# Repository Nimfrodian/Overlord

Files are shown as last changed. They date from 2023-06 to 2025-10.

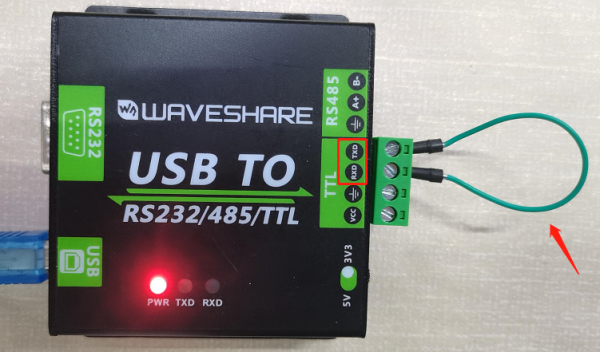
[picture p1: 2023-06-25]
Documentation/RelayBoard/Waveshare_Modbus_RTU_Relay_8ch_board/wiki webpage/Modbus RTU Relay - Waveshare Wiki_files/Serial_Module_FAQ01.png

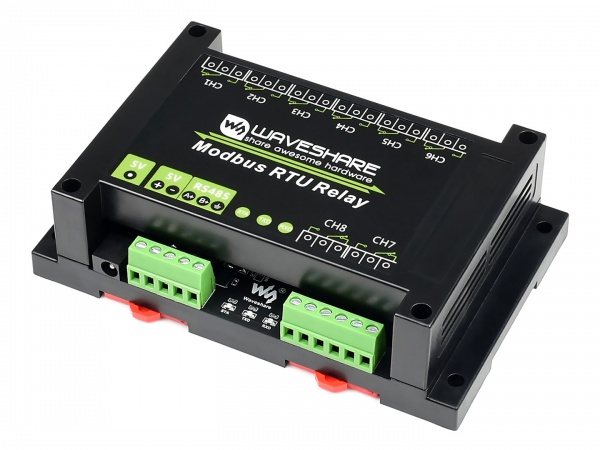
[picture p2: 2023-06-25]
Documentation/RelayBoard/Waveshare_Modbus_RTU_Relay_8ch_board/wiki webpage/Modbus RTU Relay - Waveshare Wiki_files/Modbus-RTU-Relay-1_003.jpg

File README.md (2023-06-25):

# Overlord
Code repository for the Overlord home automation system

This GitHub repository contains the code and documentation for a home automation project based on a custom board built around the ESP32-WROOM-32D processor. The board is designed to centralize home automation and provide control for various switches, low voltage devices, relay boards, power meters, and other modules. The primary goal of this project is to create a home automation system that is running as locally as possible while also providing an interface for existing home automation systems that can in turn control it in tandem.

## Features Overview
The custom board built on the ESP32 processor offers the following features:

- Digital Inputs: The board includes digital inputs that can be connected to various switches and sensors in your home. These inputs allow you to detect the state of switches and trigger automation actions based on their status.

- Digital Outputs: The board is equipped with digital outputs that can drive low voltage devices such as lights, fans, or other appliances. You can use these outputs to control the state of these devices based on your automation rules.

- Two MODBUS Lines: Two MODBUS lines are included on the board, enabling communication with relay boards and power meters. This allows you to monitor and control multiple devices and measure power consumption within your home automation system.

- CAN line: The board features a CAN (Controller Area Network) line that provides user input and control capabilities for other devices and modules. You can connect compatible devices to this line and communicate with them using the CAN protocol. This allows easy integration into any existing home automation system that supports CAN.

- Power output for other devices which can be chosen on the board and can be set to +12V, +5V, or +3.3V.

## Getting Started

To get started with this home automation project, follow these steps:

- Hardware Setup: Set up the custom board based on the ESP32 processor according to the provided documentation. Ensure that all the required connections and modules are correctly attached to the board. You can have your board easily made with the provided .7z file that you simply send to a PCB manufacturer. See Documentation for more.

- Software Setup: Install the necessary software and dependencies. This typically involves setting up the Visual Studio Code, Platformio IDE and the required libraries for programming the ESP32 board. Refer to the documentation for detailed instructions.

- Code Configuration: The code generally doesn't need modification to work. See Documentation on how the software is configured to see if you need to make any modifications.

- Upload the Code: Connect the custom board to your computer using a USB cable and upload the code to the ESP32 board using Platformio IDE the upload process for any errors and ensure successful code transfer.

- Testing and Integration: Once the code is uploaded, test the functionality of the board by interacting with the switches, devices, and modules connected to it. Verify that the digital inputs, outputs, MODBUS lines, and CAN line are working as intended.

- Customization and Expansion: Customize the code further to add additional features or integrate with other home automation systems. Expand the functionality of the project to suit your specific needs and preferences.

### Documentation
For detailed documentation, including hardware specifications, pin configurations, and usage guidelines, please refer to the Documentation folder in this repository.

### Contributing

Contributions to this home automation project are welcome! If you have ideas, suggestions, or improvements, please feel free to open an issue or submit a pull request. Let's collaborate and make home automation better together.

### License

This project is licensed under the GNU version 3.0 License. Feel free to use, modify, and distribute the code as per the terms of the license.

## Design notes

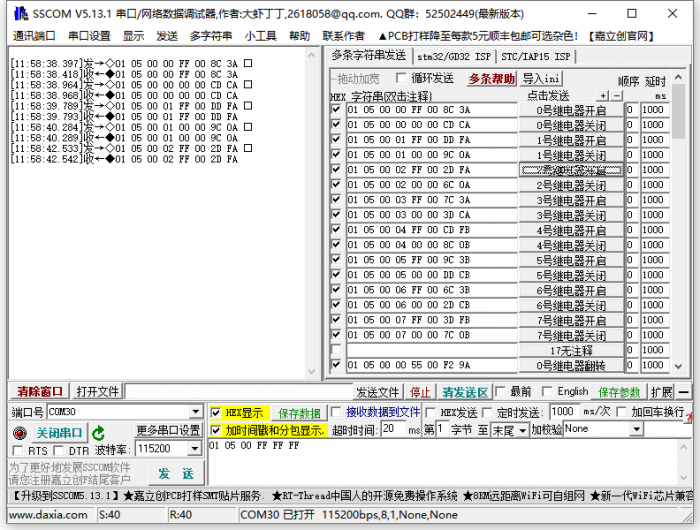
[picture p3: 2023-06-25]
Documentation/RelayBoard/Waveshare_Modbus_RTU_Relay_8ch_board/wiki webpage/Modbus RTU Relay - Waveshare Wiki_files/Modbus-RTU-Relay-2.png

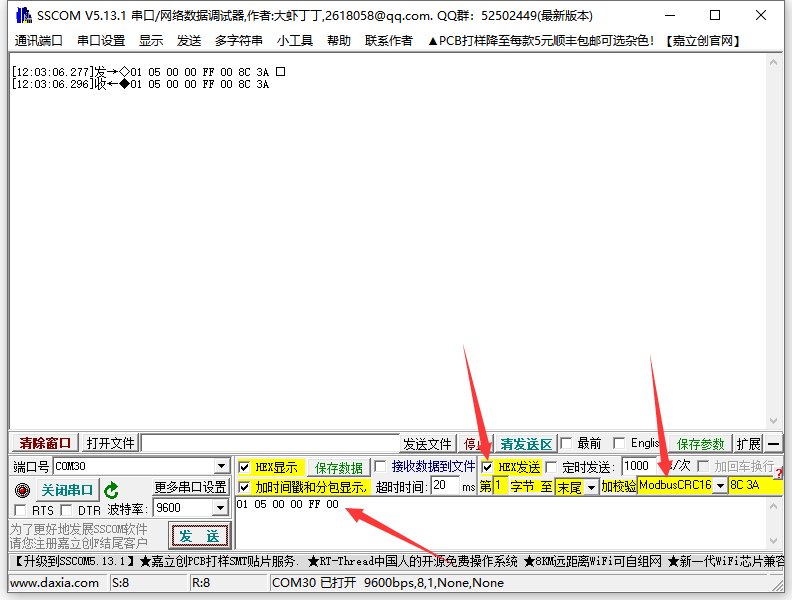
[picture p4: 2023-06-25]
Documentation/RelayBoard/Waveshare_Modbus_RTU_Relay_8ch_board/wiki webpage/Modbus RTU Relay - Waveshare Wiki_files/Modbus-RTU-Relay-3_002.png

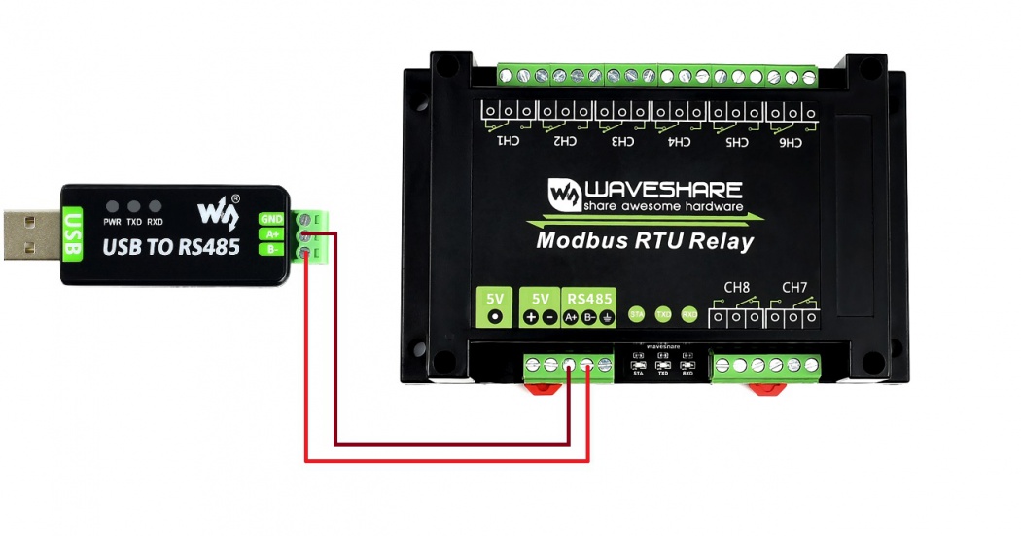
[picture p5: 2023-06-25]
Documentation/RelayBoard/Waveshare_Modbus_RTU_Relay_8ch_board/wiki webpage/Modbus RTU Relay - Waveshare Wiki_files/Modbus-RTU-Relay_connet_002.jpg

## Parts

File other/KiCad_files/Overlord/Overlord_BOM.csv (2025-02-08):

Reference | Value | Datasheet | Footprint | Qty | DNP
BOOT1,RESET1 | PTS810SJK250SMTR LFS | https://eu.mouser.com/ProductDetail/CK/PTS810SJK250SMTR-LFS?qs=Imq1NPwxi77Ow0tzRIznfA%3D%3D | OverlordCommon:PTS810SJK250SMTRLFS | 2
C1,C3,C8,C9,C12,C13,C14,C15,C16,C17,C19,C20,C21,C22,C23,C24,C25,C26,C28,C29,C30,C31,C32,C33,C34,C35,C37,C38,C39,C40,C41,C42,C43,C44,C46,C47,C48,C49,C50,C51,C52,C53 | 0.1uF | https://eu.mouser.com/ProductDetail/KYOCERA-AVX/08053C104KAT4A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 | Capacitor_SMD:C_0805_2012Metric_Pad1.18x1.45mm_HandSolder | 42
C2,C10,C11 | 10uF | https://www.mouser.se/ProductDetail/Samsung-Electro-Mechanics/CL21A106KOQNNNE?qs=349EhDEZ59qKIX0T0PKtPw%3D%3D | Capacitor_SMD:C_0805_2012Metric_Pad1.18x1.45mm_HandSolder | 3
C4,C5,C6,C7 | 1uF | https://eu.mouser.com/ProductDetail/KYOCERA-AVX/KGM21AR71E105KL?qs=Jm2GQyTW%2FbgOspZKgNqh%2Fg%3D%3D | Capacitor_SMD:C_0805_2012Metric_Pad1.18x1.45mm_HandSolder | 4
C54,C55,C56,C57 | 220uF | https://si.farnell.com/rubycon/25zl220mefc8x11-5/cap-220-f-25v-20/dp/1144699 | Capacitor_THT:CP_Radial_D8.0mm_P3.50mm | 4
D1,D2,D3,D4,D5,D6 | 1N4148 | https://www.mouser.se/ProductDetail/Taiwan-Semiconductor/TS4148-RBG?qs=5aG0NVq1C4zjFQ%2F0tPTeiA%3D%3D | Diode_SMD:D_0805_2012Metric_Pad1.15x1.40mm_HandSolder | 6
D7 | TPD2E001DZDR | https://eu.mouser.com/ProductDetail/Texas-Instruments/TPD2E001DZDR?qs=6kmNHVaEmPhk6KdNbOe6jw%3D%3D | OverlordCommon:TPD2E001DZDR | 1
DB9_IN1 | 5788792-2 | https://eu.mouser.com/ProductDetail/TE-Connectivity/5788792-2?qs=3NVJH8%2FxV2%252Bs7E8tWduUkQ%3D%3D | OverlordCommon:5788792 | 1
DB9_OUT1 | 5747844-4 | https://eu.mouser.com/ProductDetail/TE-Connectivity/5747844-4?qs=x6EjVpvqMVOIOT3ErJFDOQ%3D%3D | OverlordCommon:57478444 | 1
Dbg1,Dbg2,Dbg13,Dbg14,Dbg15,Dbg16,Dbg17,Dbg18,Dbg19,Dbg20,Dbg21,Dbg22,Dbg23,Dbg24,Dbg25,Dbg26,Dbg27,Dbg39,Dbg40,Dbg41,Dbg42,Dbg43,Dbg44,Dbg45,Dbg46,Dbg47,Dbg48,Dbg60,Dbg61,Dbg62,Dbg63,Dbg64,Dbg65,Dbg66 | Connector_Conn_01x01_Male |  | Connector_PinHeader_2.54mm:PinHeader_1x01_P2.54mm_Vertical | 34
IC1,IC2,IC3,IC4 | 74HC4052D,653 | https://assets.nexperia.com/documents/data-sheet/74HC_HCT4052.pdf | 74HC4052D653 | 4
J1,J2,J3 | 39502-1011 | https://www.molex.com/webdocs/datasheets/pdf/en-us/0395021011_TERMINAL_BLOCKS.pdf | OverlordCommon:SHDRRA11W80P0X350_1X11_3990X690X920P | 3
J4 | Conn_01x12_Pin | https://www.mouser.se/ProductDetail/538-90325-0012 | Connector_Molex:Molex_Picoflex_90325-0012_2x06_P1.27mm_Vertical | 1
J5 | Conn_01x10_Pin | ~ | Connector_PinHeader_2.54mm:PinHeader_1x10_P2.54mm_Vertical | 1
J6,J7 | Conn_01x11_Pin | ~ | Connector_PinHeader_2.54mm:PinHeader_1x11_P2.54mm_Vertical | 2
J_CAN120R1 | Conn_01x02_Male | ~ | Connector_PinHeader_2.54mm:PinHeader_1x02_P2.54mm_Vertical | 1
J_JTAG1 | FTSH-105-01-S-DV-K | https://eu.mouser.com/ProductDetail/Samtec/FTSH-105-01-S-DV-K?qs=Cqqh%252BS766wmAOq95MtbXow%3D%3D | OverlordCommon:FTSH-105-XX-YYY-DV-K | 1
J_JTAG3V3_1,J_PROG3V3_1 | Conn_01x02_Pin | ~ | Connector_PinHeader_2.54mm:PinHeader_1x02_P2.54mm_Vertical | 2
J_PROG1 | FTSH-103-01-S-DV-TR | https://eu.mouser.com/ProductDetail/Samtec/FTSH-103-01-S-DV-TR?qs=Cqqh%252BS766wm4bsLlv5ihTQ%3D%3D | OverlordCommon:FTSH-103-XX-YYY-DV-TR | 1
J_USB1 | USB_B | https://si.farnell.com/1321918?CMP=e-email-sys-shipping-GLB-Product | OverlordCommon:USB | 1
MAX485ESA+T_1,MAX485ESA+T_2 | MAX485ESA+T | https://datasheets.maximintegrated.com/en/ds/MAX1487E-MAX491E.pdf | Package_SO:SO-8_3.9x4.9mm_P1.27mm | 2
R1,R9 | 240 | https://www.mouser.se/ProductDetail/Vishay-Dale/CRCW0805240RFKEA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 | Resistor_SMD:R_0805_2012Metric | 2
R2 | 120 | https://si.farnell.com/multicomp/mcwr04x1200ftl/res-120r-1-0-0625w-thick-film/dp/2447103 | Resistor_SMD:R_0805_2012Metric_Pad1.20x1.40mm_HandSolder | 1
R3 | 0R | https://www.mouser.se/ProductDetail/Vishay-Dale/CRCW08050000Z0EA | Resistor_SMD:R_0805_2012Metric_Pad1.20x1.40mm_HandSolder | 1
R4 | 390 | https://eu.mouser.com/ProductDetail/Panasonic/ERJ-P06F3900V?qs=sGAEpiMZZMvdGkrng054t2zaCLvyUXZJqk8Bx6mV9sI%3D | Resistor_SMD:R_0805_2012Metric | 1
R5,R14,R18,R24 | 20K | ~ | Resistor_SMD:R_0805_2012Metric_Pad1.20x1.40mm_HandSolder | 4
R6,R7,R8,R19,R20,R21 | 10K | ~ | Resistor_SMD:R_0805_2012Metric_Pad1.20x1.40mm_HandSolder | 6
R10,R22 | 3K3 | ~ | Resistor_SMD:R_0805_2012Metric_Pad1.20x1.40mm_HandSolder | 2
R11 | 10k | https://si.farnell.com/vishay/crcw080510k0jneaif/res-10k-5-0-125w-0805-thick-film/dp/1739242 | Resistor_SMD:R_0805_2012Metric_Pad1.20x1.40mm_HandSolder | 1
R12 | 680 |  | Resistor_SMD:R_0805_2012Metric | 1
R13,R23 | 6K8 | ~ | Resistor_SMD:R_0805_2012Metric_Pad1.20x1.40mm_HandSolder | 2
R15,R16,R17 | 220 | https://si.farnell.com/multicomp/mchvr06jtev2200/res-220r-5-0-25w-1206-thick-film/dp/2826318 | Resistor_SMD:R_0805_2012Metric_Pad1.20x1.40mm_HandSolder | 3
R25,R26,R27,R28,R29,R30,R31,R32,R33,R34,R35,R36,R37,R38,R39,R40,R41,R42,R43,R44,R45,R46,R47,R48,R49,R50,R51,R52,R53,R54,R55,R56 | 4.7k | https://www.mouser.se/ProductDetail/YAGEO/RC0805JR-074K7P | Resistor_SMD:R_0805_2012Metric_Pad1.20x1.40mm_HandSolder | 32
SN65HVD230_1 | SN65HVD230 | https://si.farnell.com/texas-instruments/sn65hvd230dr/can-transceiver-1mbps-40-to-85deg/dp/3124671 | Package_SO:SOIC-8_3.9x4.9mm_P1.27mm | 1
SYM1,SYM2,SYM3 | Terminal plug | https://www.mouser.se/ProductDetail/Molex/39500-0011?qs=XbM9o1La6yDOmN%2F9rnqtWA%3D%3D | OverlordCommon:39500-0011 | 3
U_ESP32-S3-WROOM-1U-N16_1 | ESP32S3-Wroom | https://www.mouser.se/ProductDetail/Espressif-Systems/ESP32-S3-WROOM-1U-N16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 | PCM_Espressif:ESP32-S3-WROOM-1U | 1
U_LM317_1,U_LM317_2 | LM317_SOT-223 | https://www.mouser.se/ProductDetail/Texas-Instruments/LM317DCY?qs=5BZzbFV4k2uyLTpaIDoA2Q%3D%3D | Package_TO_SOT_SMD:SOT-223-3_TabPin2 | 2
U_TRS3232EIPWR1 | TRS3232EIPWR | https://eu.mouser.com/ProductDetail/Texas-Instruments/TRS3232EIPWR?qs=0OHPnBYoB%2FnctvQznRkgWA%3D%3D | OverlordCommon:SOP65P640X120-16N | 1

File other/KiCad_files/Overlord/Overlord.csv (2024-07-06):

Source: | C:\Users\Laptop-3070\Documents\Overlord\other\KiCad_files\Overlord\Overlord.kicad_sch
Date: | 06/07/2024 11:23:18
Tool: | Eeschema 7.0.10
Generator: | C:\Program Files\KiCad\7.0\bin\scripting\plugins/bom_csv_grouped_by_value.py
Component Count: | 108
Collated Components:
Item | Qty | Reference(s) | Value | LibPart | Footprint | Datasheet | DNP | Sim.Device | Sim.Pins
1 | 1 | 120R_enable1 | Conn_01x02_Male | Connector:Conn_01x02_Pin | Connector_PinHeader_2.54mm:PinHeader_1x02_P2.54mm_Vertical | ~
2 | 1 | C1 | 100uF | Device:C_Polarized | Capacitor_SMD:C_Elec_6.3x7.7 | ~
3 | 3 | C2, C3, C17 | 10uF | Device:C_Polarized | Capacitor_THT:CP_Radial_D4.0mm_P1.50mm | ~
4 | 1 | C4 | 100nF | Device:C | Capacitor_SMD:C_1812_4532Metric_Pad1.57x3.40mm_HandSolder | ~
5 | 2 | C5, C6 | 22uF | Device:C_Polarized | Capacitor_THT:CP_Radial_D4.0mm_P1.50mm | ~
6 | 33 | C7, C8, C9, C10, C12, C14, C15, C16, C18, C19, C20, C21, C22, C23, C24, C25, C26, C28, C29, C30, C31, C32, C33, C34, C35, C36, C37, C38, C39, C40, C41, C42, C43 | 100nF | Device:C | Capacitor_THT:C_Disc_D6.0mm_W2.5mm_P5.00mm | https://si.farnell.com/multicomp/mcfyu6104z6/cap-0-1-f-50v-y5v/dp/9411887
7 | 4 | C13, C27, C44, C45 | 220uF | Device:C | Capacitor_THT:CP_Radial_D8.0mm_P3.50mm | https://si.farnell.com/rubycon/25zl220mefc8x11-5/cap-220-f-25v-20/dp/1144699
8 | 1 | D1 | 1N5819 | Device:D_Schottky | Diode_SMD:D_SOD-123 | ~
9 | 1 | D2 | D | Device:D | Diode_SMD:D_SOD-123 | https://si.farnell.com/diodes-inc/sbr1a40s1/diode-rectifier-40v-1a-sod123/dp/2061529 |  | D | 1=K 2=A
10 | 1 | ESP1 | ESP-DevKitC-V4 | MCU_Espressif_ESP32:ESP-DevKitC-V4 | Overlord:ESP32-DevKitC-V4
11 | 2 | H1, H2 | MountingHole | Mechanical:MountingHole | MountingHole:MountingHole_3.5mm | ~
12 | 1 | J1 | RJ45x2 | Overlord-cache:74HC251D,653_RJ45x2 | Connector_RJ:RJ45_Amphenol_RJHSE538X-02
13 | 3 | J2, J5, J6 | Screw_Terminal_01x09 | Connector:Screw_Terminal_01x09 | TerminalBlockCustom:TerminalBlock_9_5.08mm_inverted | ~
14 | 1 | J3 | Conn_01x12_Female | Connector_Generic_MountingPin:Conn_01x12_MountingPin | Connector_Molex:Molex_CLIK-Mate_502386-1270_1x12-1MP_P1.25mm_Horizontal | https://si.farnell.com/molex/502386-1270/connector-rcpt-12pos-1row-1-25mm/dp/1620802
15 | 1 | J4 | Screw_Terminal_01x09 | Connector:Screw_Terminal_01x09 | TerminalBlockCustom:TerminalBlock_9_5.08mm | ~
16 | 1 | J7 | USB_B | Connector:USB_B | Connector_USB:USB_B_OST_USB-B1HSxx_Horizontal | ~
17 | 1 | J8 | USB_cable | Overlord-cache:Connector_Conn_01x04_Male | Connector_PinHeader_2.54mm:PinHeader_1x04_P2.54mm_Vertical
18 | 1 | L1 | 7447709331 | Device:L | Inductor_SMD:L_12x12mm_H8mm | https://www.we-online.com/components/products/datasheet/7447709331.pdf
19 | 1 | L2 | 4.7uH | Device:L | Inductor_SMD:L_Bourns-SRU8028_8.0x8.0mm | ~
20 | 4 | Q1, Q2, Q3, Q4 | 2N7002E | Transistor_FET:2N7002E | Package_TO_SOT_SMD:SOT-23 | http://www.diodes.com/assets/Datasheets/ds30376.pdf
21 | 4 | R1, R2, R31, R33 | 5K | Device:R | Resistor_SMD:R_0805_2012Metric_Pad1.20x1.40mm_HandSolder | ~
22 | 4 | R3, R4, R5, R15 | 10K | Device:R | Resistor_SMD:R_0805_2012Metric_Pad1.20x1.40mm_HandSolder | ~
23 | 5 | R6, R13, R14, R29, R30 | 20K | Device:R | Resistor_SMD:R_1812_4532Metric_Pad1.30x3.40mm_HandSolder | ~
24 | 1 | R7 | 120 | Device:R | Resistor_SMD:R_1812_4532Metric_Pad1.30x3.40mm_HandSolder | ~
25 | 6 | R8, R11, R12, R24, R27, R28 | 10K | Device:R | Resistor_SMD:R_1812_4532Metric_Pad1.30x3.40mm_HandSolder | ~
26 | 2 | R9, R25 | 6K8 | Device:R | Resistor_SMD:R_1812_4532Metric_Pad1.30x3.40mm_HandSolder | ~
27 | 2 | R10, R26 | 3K3 | Device:R | Resistor_SMD:R_1812_4532Metric_Pad1.30x3.40mm_HandSolder | ~
28 | 3 | R16, R17, R18 | 220 | Device:R | Resistor_SMD:R_0805_2012Metric_Pad1.20x1.40mm_HandSolder | ~
29 | 8 | RN1, RN2, RN3, RN4, RN5, RN6, RN7, RN8 | Res_network 4.7kOhm | Device:R_Pack04 | Resistor_SMD:R_Array_Convex_4x0612 | https://si.farnell.com/vishay/acasa470124701p100/res-net-array-4-7kohm-0-5-1206/dp/3974779
30 | 4 | U1, U2, U3, U4 | 74HC4052D,653 | Overlord-cache:74HC251D,653_74HC4052D,653 | Package_SO:SO-16_3.9x9.9mm_P1.27mm | http://www.ti.com/lit/gpn/sn74LS153
31 | 1 | U5 | LM2575D2T-5G | Regulator_Switching:LM2575-5.0BU | Package_TO_SOT_SMD:TO-263-5_TabPin3 | http://ww1.microchip.com/downloads/en/DeviceDoc/lm2575.pdf
32 | 1 | U6 | SN65HVD230 | Interface_CAN_LIN:SN65HVD230 | Package_SO:SOIC-8_3.9x4.9mm_P1.27mm | http://www.ti.com/lit/ds/symlink/sn65hvd230.pdf
33 | 2 | U7, U9 | MAX485ESA+T | Interface_UART:MAX485E | Package_SO:SO-8_3.9x4.9mm_P1.27mm | https://datasheets.maximintegrated.com/en/ds/MAX1487E-MAX491E.pdf
34 | 1 | U8 | AP63203WU-7 | Regulator_Switching:AP63203WU | Package_TO_SOT_SMD:TSOT-23-6 | https://www.diodes.com/assets/Datasheets/AP63200-AP63201-AP63203-AP63205.pdf

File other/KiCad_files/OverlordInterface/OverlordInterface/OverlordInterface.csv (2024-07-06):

# | Reference | Qty | Value | Footprint | DNP
1 | D1 | 1 | LED_B | LED_THT:LED_D3.0mm
2 | D2 | 1 | LED_G | LED_THT:LED_D3.0mm
3 | D3 | 1 | LED_R | LED_THT:LED_D3.0mm
4 | J1 | 1 | Conn_01x12_Female | Connector_Molex:Molex_CLIK-Mate_502386-1270_1x12-1MP_P1.25mm_Horizontal
5 | J2 | 1 | DE9_Receptacle_MountingHoles_CAN | Connector_Dsub:DSUB-9_Female_Vertical_P2.77x2.84mm_MountingHoles
6 | J3, J4, J5 | 3 | DE9_Receptacle_MountingHoles_UART | Connector_Dsub:DSUB-9_Female_Vertical_P2.77x2.84mm_MountingHoles

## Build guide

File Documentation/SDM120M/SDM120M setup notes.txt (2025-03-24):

By using the button on the SDM120M and short/long pressing it, configure the device as follows

baudrate 9600
parity None ("n")
Check for ID in code

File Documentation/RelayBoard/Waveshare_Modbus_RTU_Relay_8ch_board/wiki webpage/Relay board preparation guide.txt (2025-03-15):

This guide will help you set up the Modbus RTU Relay board to function with the Overlord system

Hardware:
- Relay board
- Power supply
- USB-to-RS485 converter

0. install SSCOM program and drivers for RS485 converter

1a. connect RS485 A connector to relay board's A connector, and same for B connector
1b. connect RS485 to PC and power on relay board

2. in SSCOM, select your COM port (check drivers if not found) for the RS485 converter
3. click openCOM button to open COM port
4. select baud rate 9600
5. read the device's current address by sending 00 03 40 00 00 01. Response should be
	YY 03 02 00 YY ## ##, where YY is device address and "## ##" is the CRC
6. set device address by sending YY 06 40 00 00 XX, where XX is the new device address
7. set baudrate to 256000 by sending 01 06 20 00 00 07 
8. change baudrate setting to 256000 in program

9. confirm changes by repeating step 5 and verifying change
10. device is now ready for use

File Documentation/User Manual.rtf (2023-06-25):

DEVELOPER MANUAL
OVERLORD HOME AUTOMATION SYSTEM

For use by developers creating, contributing to and using the Overlord Home Automation System

Created by Nimfrodian
Overview

The Overlord Home Automation System is designed to facilitate a home automation system that runs locally and can offer support for Modbus and CAN based devices as well as other devices that can be controlled directly via power supply (LED strips etc.). The system can run in a standalone configuration, but it can also be controlled via CAN in tandem. Since it can be controlled externally it can thus be controlled by other home automation systems that can implement CAN, such as Home Assistant.

Index

1.
Hardware

A custom PCB was designed to fit the ESP32-WROOM-32D based microcontroller which is at the heart of the project. The ESP board was chosen for a few reasons, the main one being accessibility as the ESP board provides several crucial features, such as fast processor speed, CAN line, and several UART lines. The second major reason was cost as ESP32 boards come cheaper than the sum cost of their parts. The boards themselves, at the time of writing, come at around 8€ while just the USB-to-UART converter costs 6€ and the processor 8€. Having the ESP32 board detachable also provides easy replaceability of the board’s main component.
The ESP32 board around which the PCB was designed is the ESP32 DEVKIT V4 featuring the ESP32-WROOM-32D processor.

The PCB design can be found in the project folder
...\Overlord\other\KiCad_files\Overlord

The PCB project can be opened in the KiCAD program, which can be obtained here
https://www.kicad.org/

For the components used on the PCB refer to the BOM within KiCAD.
The housing for the PCB is CAMDENBOSS CNMB/9/KIT Plastic Enclosure, DIN Rail, Polycarbonate, 58 mm, 90 mm, 159.2 mm, IP20
https://www.camdenboss.com/camden-boss/cnmb9kit-din-rail-module-box-kit%2c-industrial-enclosure%2c-polycarbonate-enclosure/c-23/p-18747

(Add typical system overlay here)
2.
Software

In order to upload the code, the ESP32 board used in the project the following software components are needed:
- Visual Studio Code: This program is used to modify and upload the code to the board. It can be obtained here: https://code.visualstudio.com/
o Within Visual Studio Code the following extension will need to be installed. Refer to Visual Studio Code’s Extension help on how to install them.
▪ Platformio IDE: Used to compile and upload the code to the ESP32 board
▪ C/C++: (Optional) This extension implements code browsing, highlights code, adds Intellisense and more.
▪ GitLens – Git supercharger: (Optional) This extension highlights changes made to the code
- Sourcetree: (Optional, any Git program will work). Use this program to commit changes to the code repository.
- Busmaster: (Optional) Use this program to connect to the ESP32 board via CAN connection. This will require external hardware. Another option is to use TsMaster program which again will need additional hardware. You can obtain TsMaster here https://github.com/TOSUN-Shanghai/TSMaster and the hardware that is proven to work with this project here https://openlightlabs.com/collections/frontpage/products/canable-0-4
Note: as long as the device can connect to the CAN line it should be compatible with this project

The software is designed on the AUTOSAR approach where there are three layers to it, the application layer, the real time environment layer and the basic software layer. The general layout is as such
Application layer: in this layer the CAN message composing and parsing as well as Modbus message composing and parsing logic can be found.
Real Time Environment layer: this layer connects the whole software together. It is responsible for providing the application layer with relevant data and also feeding the basic software layer with its required data
Basic Software Layer: in this layer the CAN and Modbus drivers can be found.
3.
How to use the Overlord Home Automation System

The hardware features the following interfaces:
- 2x Modbus connection
- 1x CAN connection
- 32x digital input (sense towards ground)
- 6x digital output (low-side driver)
- Power output (12V, 5V, or 3.3V – can be selected via the PCB board using a 0 Ohm resistor)

The software version 1.00.00 works as follows:
- Each of the 32 digital inputs is directly connected to its corresponding relay on the 4 relay boards, i.e., when the first digital input senses ground a Modbus message will be sent for the first relay to change state. This allows for near instantaneous change of state for the corresponding line connection.
- The two Modbus lines work on different baud rates. Modbus line that works on UART0 of the ESP32 board is called Modbus 0 and works on 256000 baud rate. This line connects the Waveshare RTU Relay boards. The other Modbus line that uses UART2 of the ESP32 board connects SDM120M power meters and runs on 9600 baud rate. Both the relay boards and the SDM120M are continuously polled for information.
- The CAN line provides information on the relay states as well as power readings from the SDM120M as they become available. It also provides the interface on which the Overlord can be controlled. See the .dbc file contains more information on what kind of messages can be expected on the CAN line. The baud rate for this connection is 250kbps.
- The 6 low-side drivers can be used to power external devices. Next to them is also the power output which can be selected via a 0 Ohm resistor. This power output can also be used to power the external device (such as the Waveshare RTU Relay board).

With this configuration it is possible to have full control over the behaviour of switches throughout the home. It is possible to turn on/off devices based on automations/time, turn on blinds, AC, etc.

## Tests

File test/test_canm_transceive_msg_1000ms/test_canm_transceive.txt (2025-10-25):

#include "test_helper.h"
#include <unity.h>
#include "canm.h"
#include "rtdb.h"
#include "mdll.h"
#include <vector>
#include <cstdio>
using namespace std;

#define TEST_ti_ms_TOTAL_EXECUTION_TIME_U32 ((tU32) 50000)

static tU32 totalMsgsSent = 0;
static tU32 totalTimeRun_ms = 0;
static vector<tCANM_MSG> messages = {};

static tB (send)(const tCANM_MSG *msg)
{
    messages.push_back(*msg);
    totalMsgsSent++;
    return NO_ERROR;
};
static tB (receive)(tCANM_MSG *msg){return NO_ERROR;};

static tU32 run_canm_runnable(void)
{
    canm_transceive_run_5ms();
    totalTimeRun_ms += TEST_ti_ms_MAIN_FUNC_CYCLE_TIME_U32;
    return totalTimeRun_ms;
}

static tS32 verify_message_ID_in_vector(uint32_t msgId)
{
    for (size_t i = 0; i < messages.size(); ++i)
    {
        if (messages[i].identifier == msgId)
        {
            return static_cast<tS32>(i);
        }
    }
    return -1; // Not found
}

static void remove_message_ID_in_vector(tU32 msgId)
{
    for (size_t i = 0; i < messages.size(); ++i)
    {
        if (messages[i].identifier == msgId)
        {
            messages.erase(messages.begin() + msgId);
            return;
        }
    }
}

static void check_new_msg_tx_and_timing()
{
    messages.clear();
    for (tU8 moduleIndx = 0; moduleIndx <= CANM_MAX_PWR_METERS_U32; moduleIndx++)
    {
        for (tU8 msgIndx = 0; msgIndx < 11; msgIndx++)
        {
            tU32 id = 0x1F5 + msgIndx + moduleIndx * 11;
            rtdb_write_tF32S((tF32SEnumT)(RTDB_MBCM_X_SDM120MREADINGS_0_AF32_0 + (msgIndx * 2) + 0 + moduleIndx * 21), 0xA5*(msgIndx+1) + moduleIndx);
            if (msgIndx < 10) rtdb_write_tF32S((tF32SEnumT)(RTDB_MBCM_X_SDM120MREADINGS_0_AF32_0 + (msgIndx * 2) + 1 + moduleIndx * 21), 0x5A*(msgIndx+1) + moduleIndx);
        }
    }

    for (tU32 ti_ms_executionTime_U32  = totalTimeRun_ms;
              ti_ms_executionTime_U32 <= (TEST_ti_ms_TOTAL_EXECUTION_TIME_U32 + totalTimeRun_ms);
              ti_ms_executionTime_U32 += TEST_ti_ms_MAIN_FUNC_CYCLE_TIME_U32)
    {
        tU32 totalRuntime_ms = run_canm_runnable();

        if ((totalRuntime_ms % 10) == 0)
        {
            // no messages
        }
        if ((totalRuntime_ms % 100) == 0)
        {
            // TODO: change timing method to be independant from test ordering
            tS32 msg0x150Pos = verify_message_ID_in_vector(0x150);
            tS32 msg0x110Pos = verify_message_ID_in_vector(0x110);
            tS32 msg0x111Pos = verify_message_ID_in_vector(0x111);
            UNITY_TEST_ASSERT_EQUAL_UINT8(true, msg0x150Pos >= 0, __LINE__, "Message ID 0x150 not found");
            UNITY_TEST_ASSERT_EQUAL_UINT8(true, msg0x110Pos >= 0, __LINE__, "Message ID 0x110 not found");
            UNITY_TEST_ASSERT_EQUAL_UINT8(true, msg0x111Pos >= 0, __LINE__, "Message ID 0x111 not found");
            remove_message_ID_in_vector(0x150);
            remove_message_ID_in_vector(0x110);
            remove_message_ID_in_vector(0x111);
        }
        if ((totalRuntime_ms % 1000) == 0)
        {
            static tU8 moduleIndx = 0;
            char text[128] = {0};

            for (tU8 msgIndx = 0; msgIndx < 11; msgIndx++)
            {
                tU32 id = 0x1F5 + msgIndx + moduleIndx * 11;
                sprintf(text, "Message ID 0x%X not found at time %d ms", id, totalRuntime_ms);
                tS32 vectorMsgIndx = verify_message_ID_in_vector(id);
                UNITY_TEST_ASSERT_EQUAL_UINT8(true, vectorMsgIndx >= 0, __LINE__, text);
                tU32 firstVar =  ((messages[vectorMsgIndx].data[3] << 24) | (messages[vectorMsgIndx].data[2] << 16) | (messages[vectorMsgIndx].data[1] << 8) | (messages[vectorMsgIndx].data[0] << 0));
                tU32 secondVar = ((messages[vectorMsgIndx].data[7] << 24) | (messages[vectorMsgIndx].data[6] << 16) | (messages[vectorMsgIndx].data[5] << 8) | (messages[vectorMsgIndx].data[4] << 0));
                sprintf(text, "firstVar incorrect at time %d ms, msgIndx %d. moduleIndx %d, msgId 0x%x", totalRuntime_ms, msgIndx, moduleIndx, id);
                UNITY_TEST_ASSERT_EQUAL_FLOAT(0xA5*(msgIndx+1) + moduleIndx, *(tF32*)((void*) &firstVar), __LINE__, text);
                sprintf(text, "secondVar incorrect at time %d ms, msgIndx %d. moduleIndx %d, msgId 0x%x", totalRuntime_ms, msgIndx, moduleIndx, id);
                UNITY_TEST_ASSERT_EQUAL_FLOAT(0x5A*(msgIndx+1) + moduleIndx, *(tF32*)((void*) &secondVar), __LINE__, text);
                remove_message_ID_in_vector(id);
            }

            moduleIndx++;
            if (moduleIndx >= CANM_MAX_PWR_METERS_U32)
            {
                moduleIndx = 0;
            }
        }

        char text[128] = {0};
        if (messages.size()) sprintf(text, "Some messages are unaccounted for. First unaccounted message's ID is 0x%X. Time: %d", messages[0].identifier, totalTimeRun_ms);
        UNITY_TEST_ASSERT_EQUAL_UINT8(0, messages.size(), __LINE__, text);
    }
}

void check_for_errors_at_the_end(void)
{
    tERRH_ERRORDATA_STR expectedError = noErrorCode;
    expectedError.moduleId = MODULE_CANM;
    test_errh_isLastErrorAsExpected(expectedError);
}

int main(int argc, char **argv) {
    UNITY_BEGIN();

    tCANM_INITDATA_STR canmInitCfg_str = {
    .ti_ms_taskDelay_U32  = TEST_ti_ms_MAIN_FUNC_CYCLE_TIME_U32,
    .canm_send_callback = send,
    .canm_receive_callback = receive,
    };
    tCANM_INITDATA_STR* canmInitCfg_pstr = &canmInitCfg_str;
    canm_init(canmInitCfg_pstr);

    RUN_TEST(check_new_msg_tx_and_timing);
    RUN_TEST(check_for_errors_at_the_end);

    UNITY_END();

    return 0;
}

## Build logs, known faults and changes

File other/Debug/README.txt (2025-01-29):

To use esp-prog you must first replace the driver via Zadig

1) Run Zadig
2) Options->List all devices
3) Select Dual RS232-HS (Interface 0)
4) Replace Driver with WinUSB

Once done you can start using the debugger via PlatformIO's "Run and Debug"

To JTAG debug ESP32-S3 it is generally easiest to simply use the builtin debugger. If that is not possible an external debugger can be used
To use an external debugger an efuse must be burned. This is done by
- installing ESP-IDF
- running the CMD environment (shows up as ESP-IDF(CMD) in Windows search)
- reading and/or checking connection by running "espefuse.py --port COM16 summary" (change COM)
- burning the fuse with "espefuse.py -p COM16 burn_efuse DIS_USB_JTAG"

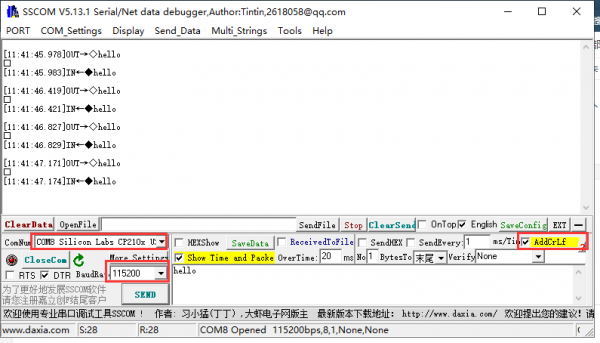
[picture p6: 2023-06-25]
Documentation/RelayBoard/Waveshare_Modbus_RTU_Relay_8ch_board/wiki webpage/Modbus RTU Relay - Waveshare Wiki_files/Serial_Module_FAQ02.png

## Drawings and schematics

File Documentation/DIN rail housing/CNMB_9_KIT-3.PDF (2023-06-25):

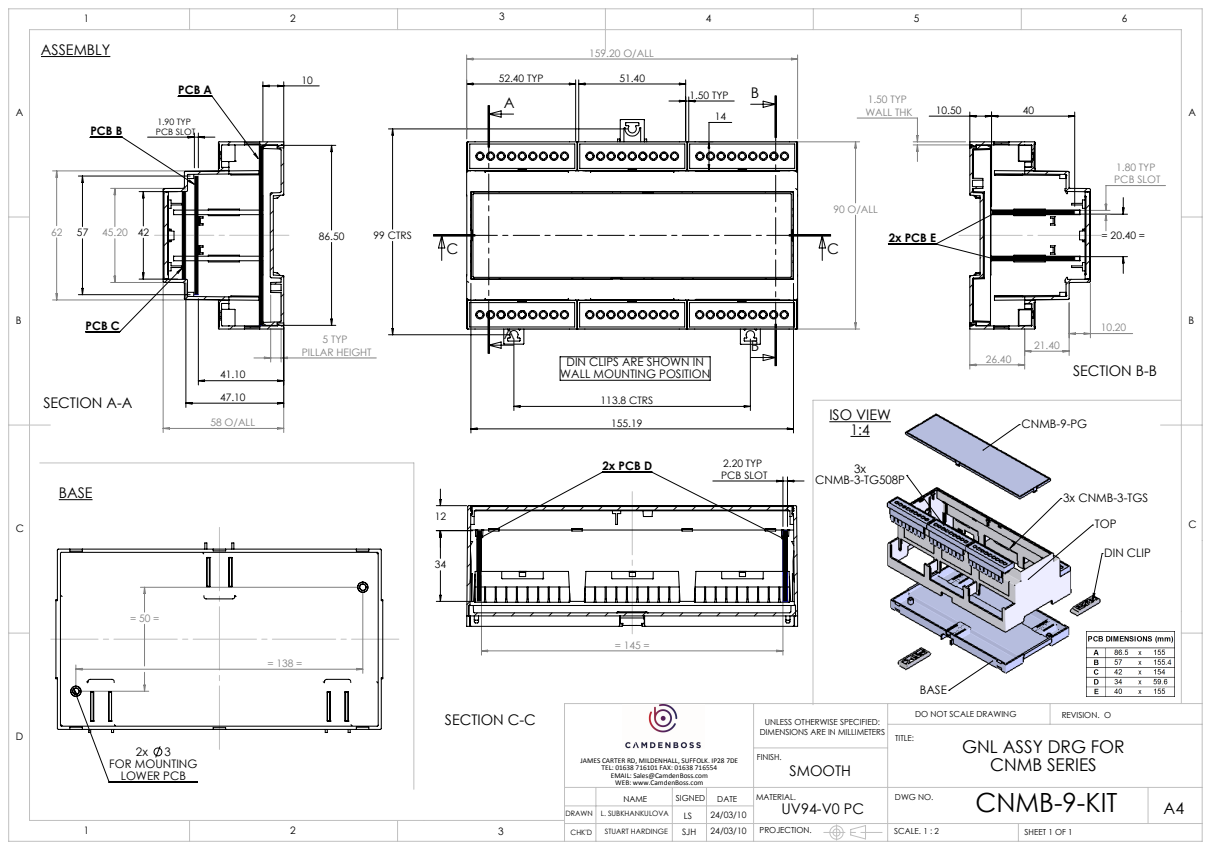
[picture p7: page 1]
90 O/ALL; 159.20 O/ALL; 113.8 CTRS; 99 CTRS; 52.40 TYP; 1.50 TYP; 5 TYP PILLAR HEIGHT; 58 O/ALL; 1.90 TYP PCB SLOT; SECTION A-A; PCB B; PCB A; PCB C; 1.50 TYP WALL THK; 1.80 TYP PCB SLOT; SECTION B-B; 2x PCB E; 2.20 TYP PCB SLOT; SECTION C-C; 2x PCB D; ISO VIEW; DIN CLIP; 3x CNMB-3-TGS; 2x 3 FOR MOUNTING LOWER PCB; NAME; SIGNED DATE; MATERIAL.; DWG NO.; SCALE. 1 : 2; SHEET 1 OF 1; REVISION. O; L. SUBKHANKULOVA; STUART HARDINGE; SJH 24/03/10

DIN CLIPS ARE SHOWN IN
WALL MOUNTING POSITION

DO NOT SCALE DRAWING
GNL ASSY DRG FOR
CNMB SERIES
CNMB-9-KIT

UNLESS OTHERWISE SPECIFIED:
DIMENSIONS ARE IN MILLIMETERS
SMOOTH

JAMES CARTER RD, MILDENHALL, SUFFOLK. IP28 7DE TEL: 01638 716101 FAX: 01638 716554 EMAIL: Sales@CamdenBoss.com

WEB: www.CamdenBoss.com

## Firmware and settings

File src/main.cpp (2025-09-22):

#include "main.h"

// Firmware version 2.xx.yy

extern "C" void app_main(void)
{
    {
        tTMRA_INITDATA_STR TmraCfg =
        {};
        tmra_init(&TmraCfg);

        tTIMH_INITDATA_STR timh_cfgData_str =
        {
            .timh_ti_us_sysTimeFunc_pfS64 = &tmra_ti_us_getCurrentTime_S64,
        };
        timh_init(&timh_cfgData_str);

        tERRH_INITDATA_STR ErrhCfg =
        {
            .ti_us_readSystemTimeCallback_S64 = tmra_ti_us_getCurrentTime_S64,
            .ti_readCurrentGlobalTimeCallback_S64 = timh_ti_readCurrentGlobalTime,
            .reportErrorCallback = ERRH_INTERNAL_CALLBACK,
        };
        errh_init(&ErrhCfg);

        tSERA_INITDATA_STR SeraCfg =
        {};
        sera_init(&SeraCfg);
        sera_print("SERA module initialized\n");

        tNVSM_INITDATA_STR NvsmCfg =
        {
            .ti_ms_taskDelay_U32 = MAIN_TI_ms_TASK_DELAY_U32, // executed in main task
        };
        nvsm_init(&NvsmCfg);
        sera_print("NVSM module initialized\n");

        tCANP_INITDATA_STR CanpCfg =
        {
            .ti_ms_taskDelay_U32 = MAIN_TI_ms_TASK_DELAY_U32, // executed in main task
        };
        canp_init(&CanpCfg);

        rtdp_init();
        sera_print("RTDB module initialized\n");

        tDMAS_INITDATA_STR DmasCfg =
        {};
        dmas_init(&DmasCfg);
        sera_print("DMAS module initialized\n");

        tDIOM_INITDATA_STR DiomCfg =
        {};
        diom_init(&DiomCfg);
        sera_print("DIOM module initialized\n");

        tMBCM_INITDATA_STR MbcmCfg =
        {};
        mbcm_init(&MbcmCfg);
        sera_print("MBCM module initialized\n");

        tDIMH_INITDATA_STR DimhCfg =
        {};
        dimh_init(&DimhCfg);
        sera_print("DIMH module initialized\n");

        sera_print("Initialization time: %lli us\n", timh_ti_us_readSystemTime_S64());
    }

    pina_setGpioAsOutput(PINA_LED_0);
    pina_setGpioAsOutput(PINA_LED_1);
    pina_setGpioAsOutput(PINA_LED_2);

    sera_print("Setting init complete LED ON\n");
    pina_setGpioLevel(PINA_LED_0, 1);

    // Main loop
    while(1)
    {
        {
            tCANM_X_CANMSGDATA_STR* rxDataPtr = canm_pstr_readCanMsgData(CAN_DMAS_COMMAND_MESSAGE);
            if (1 == rxDataPtr->canRdyForParse_tB)
            {
                dmas_canMsgParse_ev( rxDataPtr->canMsg_str.data, &rxDataPtr->canMsg_str.identifier);
                canm_x_clearFlagForCanMsgParse(CAN_DMAS_COMMAND_MESSAGE);
            }
        }

        {
            for (tU8 dmasMsgIndx = CAN_DMAS_SEND_MESSAGE0; dmasMsgIndx <= CAN_DMAS_SEND_MESSAGE15; dmasMsgIndx++)
            {
                tDMAS_MESSAGEDATA_STR preparedData = dmas_getReadyData();
                if (true == preparedData.isReady_U8)
                {
                    tCANM_X_CANMSGDATA_STR* msgPtr_pstr = canm_pstr_readCanMsgData((tCANM_CANMSGINDX_E) dmasMsgIndx);
                    msgPtr_pstr->canMsg_str.data[0] = preparedData.payload_U8[0];
                    msgPtr_pstr->canMsg_str.data[1] = preparedData.payload_U8[1];
                    msgPtr_pstr->canMsg_str.data[2] = preparedData.payload_U8[2];
                    msgPtr_pstr->canMsg_str.data[3] = preparedData.payload_U8[3];
                    msgPtr_pstr->canMsg_str.data[4] = preparedData.payload_U8[4];
                    msgPtr_pstr->canMsg_str.data[5] = preparedData.payload_U8[5];
                    msgPtr_pstr->canMsg_str.data[6] = preparedData.payload_U8[6];
                    msgPtr_pstr->canMsg_str.data[7] = preparedData.payload_U8[7];

                    msgPtr_pstr->canMsg_str.identifier = 0x20;
                    msgPtr_pstr->canRdyForTx_tB = true;
                }
                else
                {
                    break;
                }
            }
        }

        // 100ms tasks
        static uint32_t counter = 0;
        if (counter > 100)
        {
            counter = 0;
            tCANM_X_CANMSGDATA_STR* errh_canMsg0_pstr = canm_pstr_readCanMsgData(CAN_ERROR_MESSAGE0);
            tCANM_X_CANMSGDATA_STR* errh_canMsg1_pstr = canm_pstr_readCanMsgData(CAN_ERROR_MESSAGE1);
            tCANM_X_CANMSGDATA_STR* errh_canMsg2_pstr = canm_pstr_readCanMsgData(CAN_ERROR_MESSAGE2);
            tCANM_X_CANMSGDATA_STR* errh_canMsg3_pstr = canm_pstr_readCanMsgData(CAN_ERROR_MESSAGE3);

            errh_canMsg0_pstr->canMsg_str.identifier = 0x50;
            errh_canMsg1_pstr->canMsg_str.identifier = 0x51;
            errh_canMsg2_pstr->canMsg_str.identifier = 0x52;
            errh_canMsg3_pstr->canMsg_str.identifier = 0x53;

            uint8_t* canData_aU8[4] = {errh_canMsg0_pstr->canMsg_str.data,
                                    errh_canMsg1_pstr->canMsg_str.data,
                                    errh_canMsg2_pstr->canMsg_str.data,
                                    errh_canMsg3_pstr->canMsg_str.data,
                                    };

            if (true == errh_canMsgCompose_100ms(canData_aU8))
            {
                canm_x_flagCanMsgForTx(CAN_ERROR_MESSAGE0);
                canm_x_flagCanMsgForTx(CAN_ERROR_MESSAGE1);
                canm_x_flagCanMsgForTx(CAN_ERROR_MESSAGE2);
                canm_x_flagCanMsgForTx(CAN_ERROR_MESSAGE3);
            }
        }
        counter += MAIN_TI_ms_TASK_DELAY_U32;

        canm_transceive_run_5ms();

        dmas_run_5ms();

        diom_run_5ms();

        nvsm_run_5ms();

        dimh_run_5ms();

        vTaskDelay(MAIN_TI_ms_TASK_DELAY_U32 / portTICK_PERIOD_MS);
    }
}

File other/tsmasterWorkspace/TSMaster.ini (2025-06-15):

[TSMaster]
LogVerbose=6
ConfFile=D:\Projects\TOSUN\Projects\TSMaster\bin\Templates\ProjectConfigurations\CAN Bus Measurement.T7z
Bounds=1718,0,3440,1400
Maximized=0
DisplayHex=1
DisplaySym=1
Skin=
SkinPalette=
ColorfulMDI=0
Magnetic=1
TSMasterVersion=2023.9.22.972
DebugMode=0
DelConfOnFormDel=1
AutoSaveBeforeRun=0
AutoCopyDBToLocal=0
CustomFont=
TraceFont=
ShowTabGroups=1
DisableResize=0
AutoGenConstDef=0
AutoGenDBConstDef=0
DisableCrashDialog=0
UseOutputDbg=0
SelTxSgn=1
AutoHandleFlexRayUB=1
AutoSavePrj=0
DelHistoryConfOnSave=1

[OnlineReplay]
CANCount=0

[Pg0]
Count=4
f0=TfrmCANStatistics,0,52,52,257,377,141,264,349,315,1
f1=TfrmCANFDTransmit,0,0,615,863,565,375,63,1108,608,1
f2=TfrmCANFDTrace,0,0,-2,863,617,152,82,1358,523,1
f3=TfrmGraphics,0,863,-2,856,1182,157,198,936,462,1
f4=TfrmCANFDTransmit,0,0,415,1037,406,375,63,1108,608,1

[Pg1]
Count=3
f0=TfrmCANStatistics,0,741,0,765,277,141,264,349,315,1
f1=TfrmSystemMsgs,0,741,277,765,345,1013,51,853,961,1
f2=TfrmCANDatabase,0,0,0,741,622,160,133,951,594,1

[MeasurementController]
MCount=22
M0=0,1,131,-1,0,TfrmSystemMsgs,System Messages
M1=0,1,122,-1,1,TfrmCANFDTrace,CAN / CAN FD Trace
M2=0,1,50,-1,2,TfrmCANFDTransmit,CAN / CAN FD Transmit
M3=0,1,124,-1,3,TfrmGraphics,Graphics
M4=0,1,130,-1,4,TfrmCANDatabase,CAN Database
M5=0,1,128,-1,5,TfrmCANStatistics,CAN Statistics
M6=0,1,127,-1,6,TfrmLogging,Bus Logging
M7=-1,1,124,-1,7,TfrmGraphics,Deleted: Graphics
M8=-1,1,177,-1,8,TfrmNumeric,Deleted: Numeric
M9=0,1,66,-1,9,TfrmMeasurementSetup,Measurement Setup
M10=0,1,129,-1,10,TfrmPlayback,Bus Playback
M11=-1,1,124,-1,11,TfrmGraphics,Deleted: Graphics
M12=0,1,93,-1,12,TfrmSTIM,Stimulation
M13=0,1,155,-1,13,TfrmPanel,Panel
M14=0,1,146,-1,14,TfrmCCodeEditor,C Script Editor [CCode6743]
M15=0,1,180,-1,15,TfrmAutomationModule,Graphic Program 2920
M16=0,1,100,-1,16,TfrmCANoeController,CANoe Controller
M17=0,1,117,-1,17,TfrmSignalAnalyzer,Signal Comparer
M18=0,1,29,-1,18,TfrmExcelTestSystem,Excel Test Module [Test2339]
M19=0,1,47,-1,19,TfrmCalibrationCurve,Parameter Curve
M20=0,1,188,-1,20,TfrmToolboxBuilder,TOSUN Toolbox design environment
M21=0,1,15,-1,21,TfrmSystemVarMgmt,System Variable Management

[SystemMsgOptions]
MaxLines=100000
AutoStart=0
MDI=1
CaptionRenamed=0
IsExternal=0
Caption=System Messages
Priority=100
LoadMs=154
UICommon=0,-1,0,0,U3lzdGVtIE1lc3NhZ2Vz,100,157,408707419642964668
UIFilter=

[CANFDTraceOptions]
AutoStart=0
MDI=1
CaptionRenamed=0
IsExternal=0
Caption=CAN / CAN FD Trace
MaxLines=2049
DynTextColor=1
AutoScroll=1
ChronologicalMode=0
RelativeTimeMode=1
Protocol=0
Rate=2
FilterStr=
FilterIsPass=1
FilterEnabled=0
FilterChannel=0
IdRemember0=512,504,524,151,502,523,352,513,501,
IdRemember1=
IdRemember2=
IdRemember3=
IdRemember4=
IdRemember5=
IdRemember6=
IdRemember7=
IdRemember8=
IdRemember9=
IdRemember10=
IdRemember11=
IdRemember12=
IdRemember13=
IdRemember14=
IdRemember15=
IdRemember16=
IdRemember17=
IdRemember18=
IdRemember19=
IdRemember20=
IdRemember21=
IdRemember22=
IdRemember23=
IdRemember24=
IdRemember25=
IdRemember26=
IdRemember27=
IdRemember28=
IdRemember29=
IdRemember30=
IdRemember31=
TimeWidth=149
ChnWidth=39
IDWidth=66
FPSWidth=43
NameWidth=170
TypeWidth=80
DirWidth=40
DLCWidth=40
DLenWidth=90
BRSWidth=40
ESIWidth=40
DataWidth=1800
TimeVis=1
ChnVis=0
IDVis=1
FPSVis=1
NameVis=1
TypeVis=0
DirVis=1
DLCVis=0
DLenVis=0
BRSVis=0
ESIVis=0
DataVis=1
Priority=100
LoadMs=88
SyncToken=DEFAULT
CounterWidth=100
CounterVis=0
DateWidth=120
PGNWidth=112
NodeWidth=150
SrcWidth=50
DstWidth=60
PrioWidth=55
InterpWidth=200
DateVis=0
PGNVis=0
NodeVis=0
SrcVis=0
DstVis=0
PrioVis=0
InterpVis=0

[CAN_Databases]
AutoStart=0
MDI=1
CaptionRenamed=0
IsExternal=0
Caption=CAN Database
HWChnCount=2
DBFilesCount=1
DBOriCount=1
ChnCANCount=1
Priority=100
LoadMs=146
PropertyHeight=298
PropertyVisible=1
UICommon=0,-1,0,0,Q0FOIERhdGFiYXNl,100,150,3800480889012235631
UIFilter=
DBFiles0=.\DB\CAN\CAN_database.pdbc
DBOri0=..\CAN_database.dbc
ChnCAN0=0

[CANStat]
AutoStart=0
MDI=1
CaptionRenamed=0
IsExternal=0
Caption=CAN Statistics
Priority=100
LoadMs=32
UICommon=0,-1,0,0,Q0FOIFN0YXRpc3RpY3M_,100,35,51515674202303650
UIFilter=

[ChannelMappings]
CANChnCount=1
CAN0=0,0,9,0,0,-1,0,250,2000,TSMaster,
LINChnCount=0
FlexRayChnCount=0
EthernetChnCount=0

[Hardware]
ScanVendorTOSUN=0
ScanVendorVector=0
ScanVendorPeak=0
ScanVendorKvaser=0
ScanVendorZLG=0
ScanVendorIntrepidcs=0
ScanVendorCANable=1
AutoStart=0
MDI=0
CaptionRenamed=0
IsExternal=0
Caption=Hardware Configuration
Priority=100
LoadMs=77
UICommon=0,0,0,0,SGFyZHdhcmUgQ29uZmlndXJhdGlvbg__,100,88,96827417675166801
UIFilter=

[PluginManager]
ExternalCount=0

[BusStatistics]
Enabled=1

[UserVariables]
Count=0

[Debug]
OutputLeak=1

[TS_MAPPING]
AutoStart=0
MDI=0
CaptionRenamed=0
IsExternal=0
Caption=TS Channel Mapping
Priority=100
LoadMs=55
UICommon=0,0,0,0,VFMgQ2hhbm5lbCBNYXBwaW5n,100,73,5685802031077544260
UIFilter=
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

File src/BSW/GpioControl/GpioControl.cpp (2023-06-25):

#include "GpioControl.h"

static bool _gpioState[NUM_OF_INPUT_INDX] = {0};            // holds end result
static bool _gpioOutState[NUM_OF_GPIO_OUTPUTS] = {0};       // holds outputs for GPIO out abstraction
static uint8_t _gpioCntr[NUM_OF_INPUT_INDX] = {0};          // increments or decrements based on GPIO state.
static uint8_t _debounceTimer_ms[NUM_OF_INPUT_INDX] = {0};  // holds debounce timer. Decrements by task execution period each call, if not 0
const uint8_t _sortedGpioIndxs[NUM_OF_INPUT_INDX] =         // sorted array indexes. Looping _gpioState using this array as index will result in proper reading from GPIO
{
    INPUT_INDX_00,
    INPUT_INDX_01,
    INPUT_INDX_02,
    INPUT_INDX_03,
    INPUT_INDX_04,
    INPUT_INDX_05,
    INPUT_INDX_06,
    INPUT_INDX_07,
    INPUT_INDX_08,
    INPUT_INDX_09,
    INPUT_INDX_10,
    INPUT_INDX_11,
    INPUT_INDX_12,
    INPUT_INDX_13,
    INPUT_INDX_14,
    INPUT_INDX_15,
    INPUT_INDX_16,
    INPUT_INDX_17,
    INPUT_INDX_18,
    INPUT_INDX_19,
    INPUT_INDX_20,
    INPUT_INDX_21,
    INPUT_INDX_22,
    INPUT_INDX_23,
    INPUT_INDX_24,
    INPUT_INDX_25,
    INPUT_INDX_26,
    INPUT_INDX_27,
    INPUT_INDX_28,
    INPUT_INDX_29,
    INPUT_INDX_30,
    INPUT_INDX_31,
};

void CtrlGpio_init(void)
{
    // set all gpio input pins as INPUT
    for (uint8_t gpioInIndx = 0; gpioInIndx < NUM_OF_GPIO_INPUTS; gpioInIndx++)
    {
        gpio_set_direction(GPIO_IN[gpioInIndx], GPIO_MODE_INPUT);
    }

    // set all gpio selection pins as OUTPUT
    for (uint8_t gpioInSelIndx = 0; gpioInSelIndx < NUM_OF_GPIO_IN_SEL; gpioInSelIndx++)
    {
        gpio_reset_pin(GPIO_IN_SEL[gpioInSelIndx]);
        gpio_set_direction(GPIO_IN_SEL[gpioInSelIndx], GPIO_MODE_OUTPUT);
    }

    // reset all output pins functions so they can be set as OUTPUT and set them as OUTPUT
    for (uint8_t gpioOutIndx = 0; gpioOutIndx < NUM_OF_GPIO_OUTPUTS; gpioOutIndx++)
    {
        gpio_reset_pin(GPIO_OUT[gpioOutIndx]);
        gpio_set_direction(GPIO_OUT[gpioOutIndx], GPIO_MODE_OUTPUT);
    }

    // reset all debug output pins functions so they can be set as OUTPUT and set them as OUTPUT
    for (uint8_t gpioOutDbgIndx = 0; gpioOutDbgIndx < GPIO_OUT_DEBUG_NUM_OF_INDX; gpioOutDbgIndx++)
    {
        gpio_reset_pin(GPIO_OUT_DEBUG[gpioOutDbgIndx]);
        gpio_set_direction(GPIO_OUT_DEBUG[gpioOutDbgIndx], GPIO_MODE_OUTPUT);
    }

    // create reading task
    xTaskCreatePinnedToCore(
    CtrlGpio_read,    // Function that should be called
    "CtrlGpio_read",   // Name of the task (for debugging)
    8192,            // Stack size (bytes)
    NULL,            // Parameter to pass
    1,               // Task priority
    NULL,            // Task handle
    0                // run on core 0

    );

    // create writing task
    xTaskCreatePinnedToCore(
    CtrlGpio_write,     // Function that should be called
    "CtrlGpio_write",   // Name of the task (for debugging)
    1024,            // Stack size (bytes)
    NULL,            // Parameter to pass
    1,               // Task priority
    NULL,            // Task handle
    0                // run on core 0
    );
}

/**
 * @brief Function checks if input variable needs to be changed as part of debouncing
 * @param inputIndx input index of the input variable. Goes from 0 to NUM_OF_INPUT_INDX
 * @param gpioSt the current state of the input variable as read from GPIO
 * @return (void)
 */
static void checkInputForChange(CtrlGpio_inputIndxType inputIndx, bool gpioSt)
{
    // proceed if this input is not on debounce timer
    if (0 == _debounceTimer_ms[inputIndx])
    {
        // delete the appropriate counter. 0x0F bits are "1" counter, 0xF0 bits are "0" counter
        _gpioCntr[inputIndx] &= (0x0F << (4 * !gpioSt));

        // if gpio state is different than saved
        if (gpioSt != _gpioState[inputIndx])
        {
            // if previous state is different and not enough samples are yet taken then increment the appropriate counter
            if (NUM_OF_SAMPLES_FOR_STATE_CHANGE > (0x0F & (_gpioCntr[inputIndx] >> (4 * !gpioSt))))
            {
                _gpioCntr[inputIndx] += 0x01 << (4 * !gpioSt);
            }

            // save the new state as enough samples were taken and add the debounce time
            if (NUM_OF_SAMPLES_FOR_STATE_CHANGE == (0x0F & (_gpioCntr[inputIndx] >> (4 * !gpioSt))))
            {
                // save the new state
                _gpioState[inputIndx] = gpioSt;

                // set the debounce timer
                _debounceTimer_ms[inputIndx] = DEBOUNCE_TIME_MS;
            }
        }
    }
    else // debounce time is active and decrement the timer by task delay
    {
        _debounceTimer_ms[inputIndx] -= CTLR_GPIO_TASK_DELAY_TIME_MS;
    }
}
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

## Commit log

2023-06-25 FW version 1.00.00: - initial release
    [Overlord.kicad_pcb, Overlord.sch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]
2023-07-02 Reworked DIO - GPIO output now works on PWM basis, no longer just on/off - Added CAN support GPIO. GPIO input now sent to CAN and GPIO output can be controlled via CAN - minor code cleanup
    [ComModbus.cpp, main.cpp]
2023-07-16 Added support for multiple Waveshare relay boards Minor code fixes MODBUS 0 on UART0 now sends relay commands in a circular fashion as opposed to when message is ready to be sent (as MODBUS 2 on UART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
    [Overlord.sch]
2023-07-27 Fixed issue where messages would be ignored by relay boards since the Rs485 line would not go into recessive state
    [ComModbus.cpp]
2023-07-28 Fixed GPIO bitmapping issue - relays now respond to their corresponding GPIO pin
2023-08-02 Added GPIO disable control for relays
2023-09-08 Changed relay control from fast as possible to 2.5s update time with updates when needed Changed GPIO input timings
2023-12-01 Reworked UARTS - free'd up UART0, removed PWM outputs
    [ComModbus.cpp, main.cpp]
2023-12-03 Added some basic CLI now that UART0 is freed up
2023-12-03 Added time print to dev_sts
2023-12-07 renamed modbus channels to better reflect uarts behind
2023-12-13 minor fixes, updated CAN database for external dimmer module
    [ComModbus.cpp]
2023-12-15 Added LED pins for quick status display, updated schematic (still need to update PCB),
    [Overlord.kicad_pcb, Overlord.sch]
2024-02-13 Project compiles, fixed compiler warnings,
    [main.cpp]
2024-07-06 Finalised ver1.0 revC of PCB Added interface PCB
    [Overlord.csv, Overlord.kicad_pcb, Overlord.kicad_sch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]
2024-07-06 Added gerber files
    [Overlord-B_Cu.gbl, Overlord-B_Mask.gbs, Overlord-B_Paste.gbp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]
2024-07-16 Modified project to be based on az-...-V4 board, fixed Dio lib on depending on outside sources, added waveforms project
    [ComModbus.cpp, TSMaster.ini]
2024-09-14 temp changes
    [Overlord.kicad_sch]
2025-01-29 pre ESP32-S3 migration
    [Overlord.kicad_sch]
2025-02-08 sent to production
    [InputMux.kicad_sch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]
2025-02-25 sent to production with fixes
    [InputMux.kicad_sch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]
2025-03-12 updated DIO ordering due to change in hardware connections commented out crashing Rte_Cli_run() function
    [TSMaster.ini, UI.ini, main.cpp]
2025-03-15 Fixed program crashing from CLI implementation by replacing it with sera module from Dimmer Added relay board setup guide
    [ComModbus.cpp, TSMaster.ini, main.cpp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]
2025-04-13 finalised DIO module implementation TODO: fix DMAS to properly communicate via CAN
    [TSMaster.ini, UI.ini, diom.cpp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]
2025-04-13 Added relay control TODO: add support for more modules TODO: connect with GPIO inputs for control
2025-04-13 Integrated GPIO states into relay control TODO: add relay invert request
    [TSMaster.ini, UI.ini, mbcm.cpp]
2025-04-14 Modified mbcm to facilitate up to 16 relay boards
2025-04-14 Added CAN message transmit for GPIO and relay states
2025-04-14 added relay inversion logic, fixed a bug with relay status sending
    [TSMaster.ini, mbcm.cpp]
2025-04-16 Upgraded RTDB to include CRC calculations, moved rtdb module inits into rtdb init Fixed an issue where Modbus control wouldn't relinquish DE/RE signal after signal transmission
    [diom.cpp, mbcm.cpp, mbcm.h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]
2025-04-18 Added SDM120M power meter support Updated project to use compile-time module IDs instead of runtime setup
2025-04-21 fixed nvsm issue where it would constantly commit to EEPROM added pre-run to modbus task so that it checks the current state on startup
    [mbcm.cpp, mbcm.h]
2025-06-15 Sent for PCB production, ver 2.1 rev A
    [InputMux.kicad_sch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]
2025-08-27 Fixed PCB - changed modbus H/L to A/B - changed RS485 IC to a cheaper variant, fixed pullup resistors - added pullup on boot pin GPIO0 - removed unused power supplies and rerouted USB+5V for better v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
    [InputMux.kicad_sch, Overlord.kicad_pcb, Overlord.kicad_sch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]
2025-08-27 minor PCB update
    [Overlord.kicad_sch]
2025-08-28 returned 10k pullup on RO for Modbus as testing showed insufficient pull without
    [Overlord.kicad_sch]
2025-09-22 Reworked for testing - basic testing approach passing
    [ComModbus.cpp]
2026-08-17 added apparent power to CAN .dbc
